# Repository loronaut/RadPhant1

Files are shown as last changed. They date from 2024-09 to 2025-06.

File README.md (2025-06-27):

# RadPhant1

**Rad**iomic **Phant**om version **1** was developed by researchers affiliated with BC Cancer and the University of British Columbia to evaluate radiomic feature consistency of cross-centre computed tomography images. 
Design files and fabrication details are available in SolidWorks and STEP format.

*Lorna Tu, Hervé HF Choi, Haley Clark, Bradford Gill, Scott Young, Samantha AM Lloyd; Evaluating consistency of radiomic features derived from CT images: a cross-centre phantom study, Journal of Applied Clinical Medical Physics (Accepted June 2025)*

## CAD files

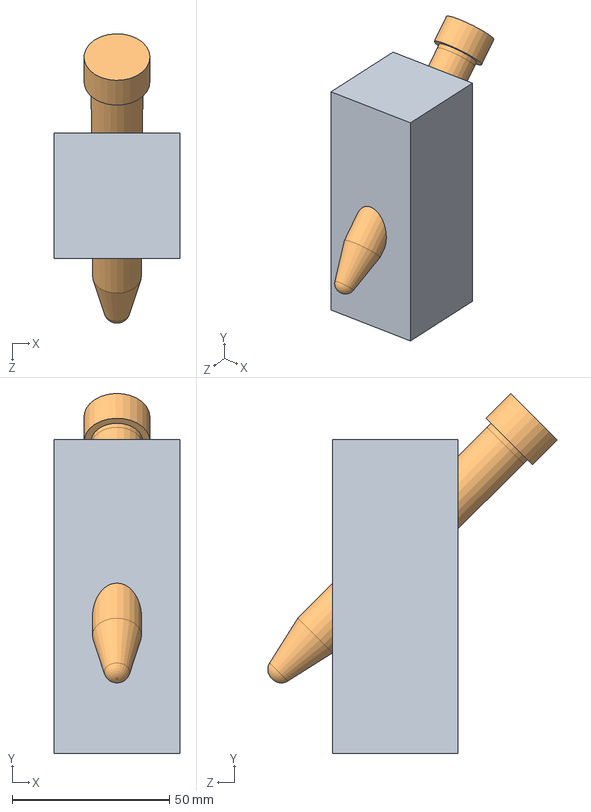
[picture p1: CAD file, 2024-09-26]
test tube block v3.SLDASM
40.0 x 114.6 x 92.1 mm
block v3
test tube v3

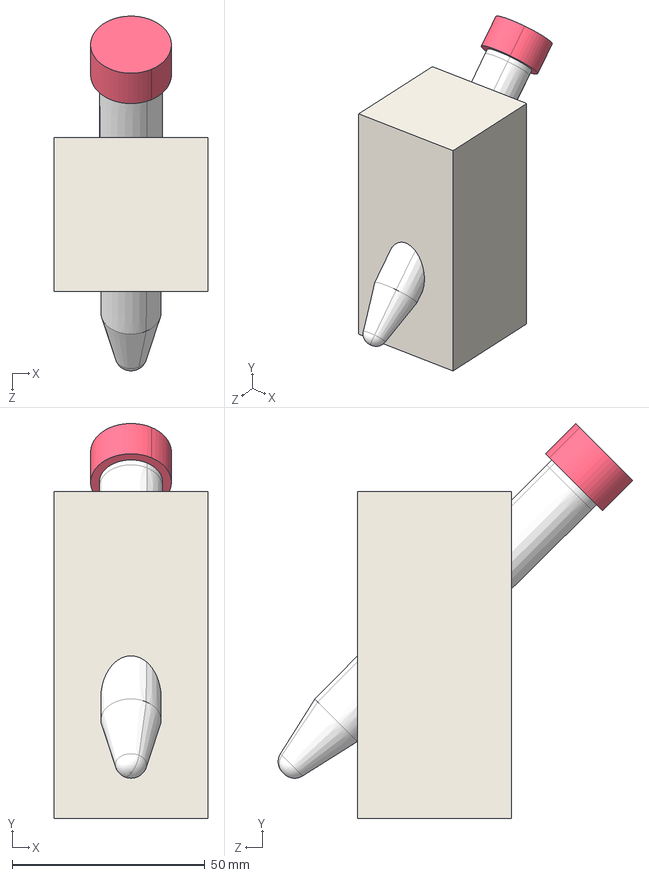
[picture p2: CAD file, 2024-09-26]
RE_ Test Tube Block STEP/test tube block assembly v3.STEP
40.0 x 102.6 x 92.1 mm
block v3
test tube v3

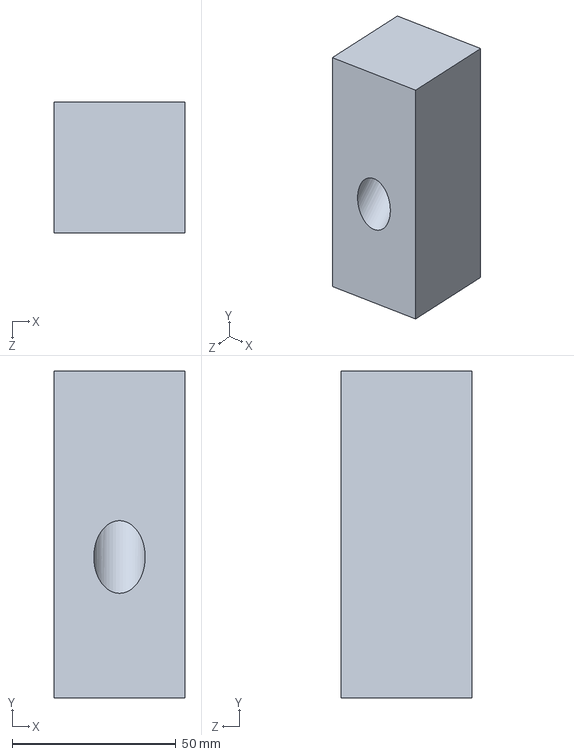
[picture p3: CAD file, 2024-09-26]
block v3.SLDPRT
40.0 x 100.0 x 40.0 mm

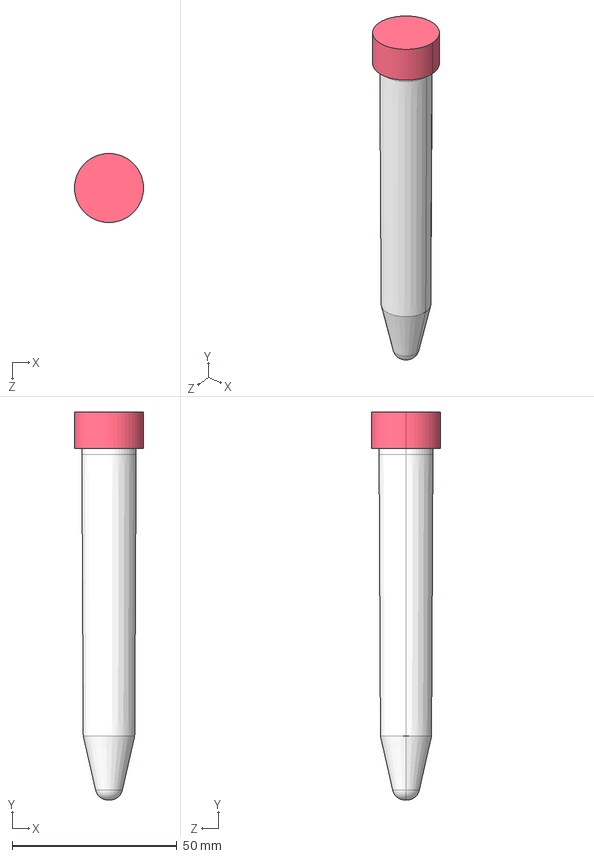
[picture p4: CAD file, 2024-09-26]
RE_ Test Tube Block STEP/test tube v3.STEP
21.0 x 117.9 x 21.0 mm

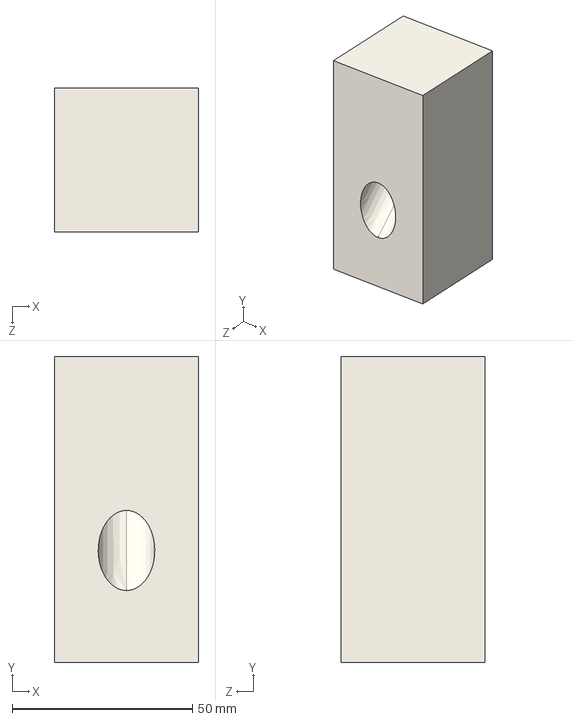
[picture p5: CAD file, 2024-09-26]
RE_ Test Tube Block STEP/block v3.STEP
40.0 x 85.0 x 40.0 mm

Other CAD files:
test tube v3.SLDPRT
test tube block v3 REV 2.SLDDRW

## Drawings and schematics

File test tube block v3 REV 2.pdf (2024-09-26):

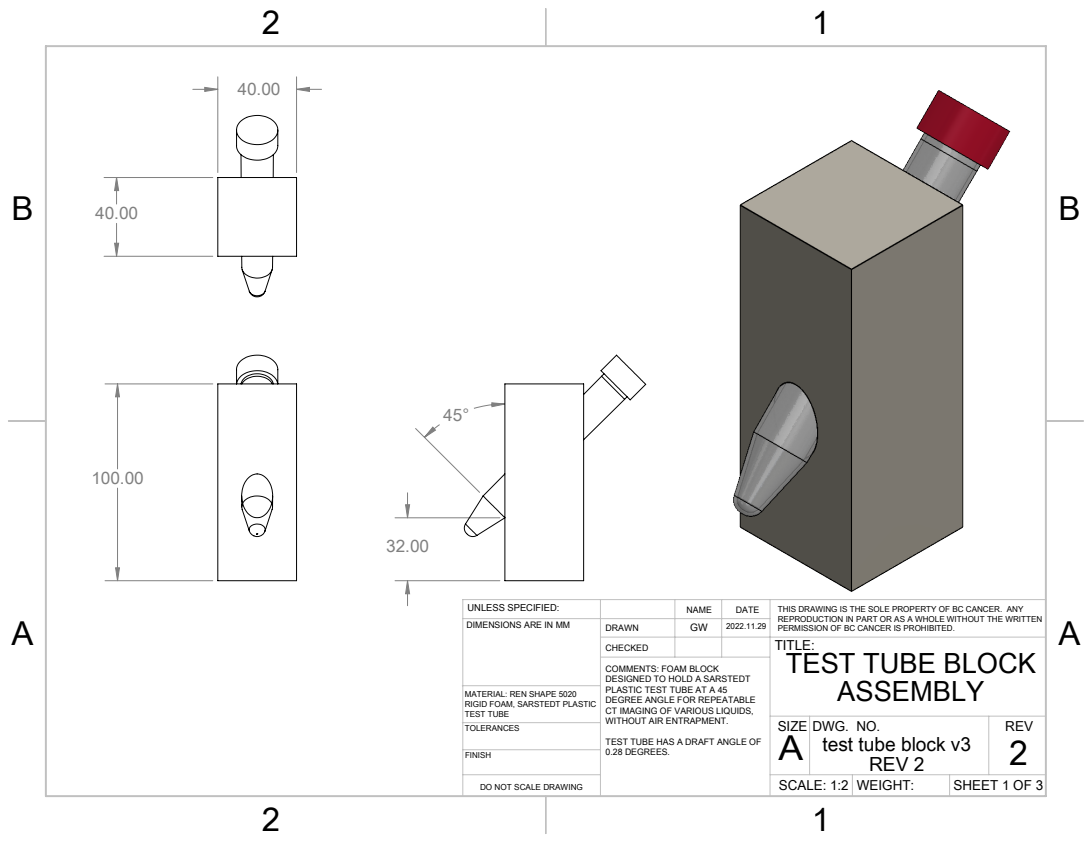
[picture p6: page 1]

UNLESS SPECIFIED: | | NAME | DATE | THIS DRAWING IS THE SOLE PROPERTY OF BC CANCER. ANY REPRODUCTION IN PART OR AS A WHOLE WITHOUT THE WRITTEN PERMISSION OF BC CANCER IS PROHIBITED.
DIMENSIONS ARE IN MM | DRAWN | GW | 2022.11.29

CHECKED | | | TITLE: TEST TUBE BLOCK ASSEMBLY

COMMENTS: FOAM BLOCK
DESIGNED TO HOLD A SARSTEDT
PLASTIC TEST TUBE AT A 45
DEGREE ANGLE FOR REPEATABLE
CT IMAGING OF VARIOUS LIQUIDS,
WITHOUT AIR ENTRAPMENT.
TEST TUBE HAS A DRAFT ANGLE OF
0.28 DEGREES.

MATERIAL: REN SHAPE 5020
RIGID FOAM, SARSTEDT PLASTIC
TEST TUBE
TOLERANCES

SIZE A | DWG. NO. test tube block v3 REV 2 | REV 2

DO NOT SCALE DRAWING | | SCALE: 1:2 | WEIGHT: | SHEET 1 OF 3

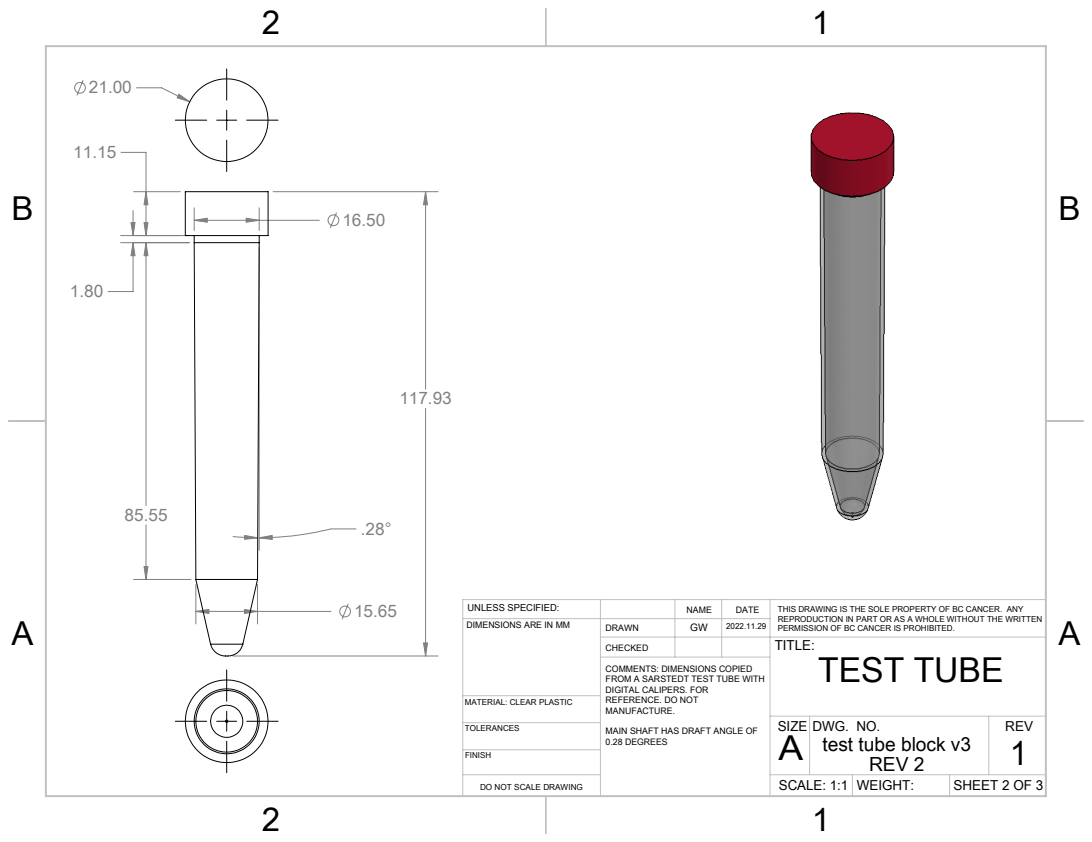
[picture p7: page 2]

UNLESS SPECIFIED: | | NAME | DATE | THIS DRAWING IS THE SOLE PROPERTY OF BC CANCER. ANY REPRODUCTION IN PART OR AS A WHOLE WITHOUT THE WRITTEN PERMISSION OF BC CANCER IS PROHIBITED.
DIMENSIONS ARE IN MM | DRAWN | GW | 2022.11.29
CHECKED | | | TITLE: TEST TUBE

COMMENTS: DIMENSIONS COPIED
FROM A SARSTEDT TEST TUBE WITH
DIGITAL CALIPERS. FOR
REFERENCE. DO NOT
MANUFACTURE.
MAIN SHAFT HAS DRAFT ANGLE OF
0.28 DEGREES

MATERIAL: CLEAR PLASTIC

SIZE A | DWG. NO. test tube block v3 REV 2 | REV 1

SCALE: 1:1 | WEIGHT:

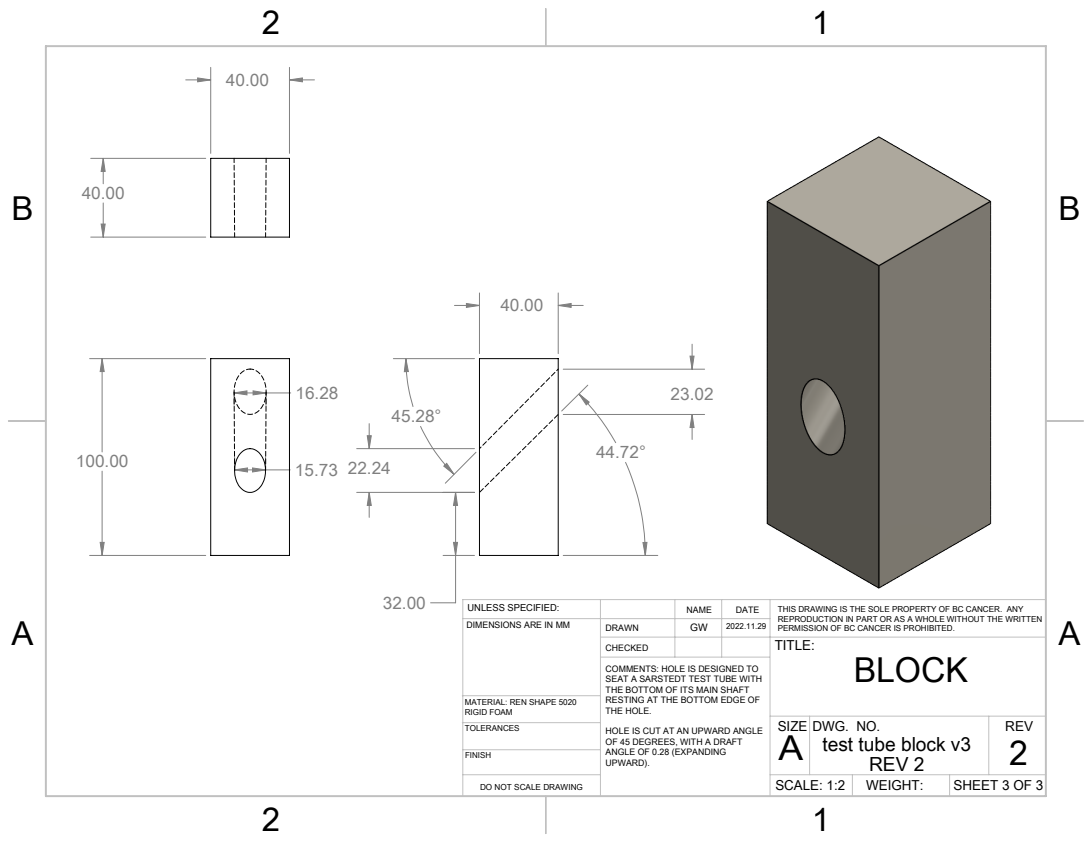
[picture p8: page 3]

UNLESS SPECIFIED: | | NAME | DATE | THIS DRAWING IS THE SOLE PROPERTY OF BC CANCER. ANY REPRODUCTION IN PART OR AS A WHOLE WITHOUT THE WRITTEN PERMISSION OF BC CANCER IS PROHIBITED.
DIMENSIONS ARE IN MM | DRAWN | GW | 2022.11.29
CHECKED | | | TITLE: BLOCK

COMMENTS: HOLE IS DESIGNED TO
SEAT A SARSTEDT TEST TUBE WITH
THE BOTTOM OF ITS MAIN SHAFT
RESTING AT THE BOTTOM EDGE OF
THE HOLE.
HOLE IS CUT AT AN UPWARD ANGLE
OF 45 DEGREES, WITH A DRAFT
ANGLE OF 0.28 (EXPANDING
UPWARD).

MATERIAL: REN SHAPE 5020
RIGID FOAM
TOLERANCES

SIZE A | DWG. NO. test tube block v3 REV 2 | REV 2

SCALE: 1:2 | WEIGHT:

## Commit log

2024-09-26 Add CAD files and design PDF
    [block v3.SLDPRT, test tube block v3 REV 2.SLDDRW, test tube block v3.SLDASM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]
2024-09-26 Add STEP files
    [block v3.STEP, test tube block assembly v3.STEP, test tube v3.STEP]
